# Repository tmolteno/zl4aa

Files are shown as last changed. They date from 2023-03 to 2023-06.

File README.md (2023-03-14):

# ZL4AA Radio Projects

Author: Tim Molteno (ZL4TCM)

Some very basic radios, developed as a way to learn about radio.

## SDR

Very basic radio project. It uses the CH32V305RBT6 RISC-V microprocessor (http://www.wch-ic.com/downloads/CH32V20x_30xDS0_PDF.html). It has the following features
made by Nanjing Qinheng Microelectronics Co. 

* 144 MHz 32-bit RISC-V core (IMAFC instructions)
* Single cycle multiply and hardware division (FPU)
* 64K SRAM
* 4 Op Amps
* 2 x 12-bit DAC !MHz (Dual Channel Mode available for Baseband)
* 2 x 12-bit ADC 1MHz

Reference manual (http://www.wch-ic.com/downloads/CH32FV2x_V3xRM_PDF.html)

### IMAFC

Set of RISC-V instruction extensions.

Integer (M) multiply and divide.
Atomic (A) instructions
Floating Point (F) single-precision
Compressed (C) instructions.

## Architecture

A local oscillator with I/Q outputs.

A switching I/Q mixer to zero IF.

40 dB LNA on Antenna Input for RX.

DAC I,Q -> MIXER -> HPF -> PA

## Gui.

SPI OLED screen, LED, Button1, Button2, Morse Key. Beep through speaker.

## Basic 6m Morse TX

Set LO to 50 MHz. 

Button 1. Increase f
Button 3. Decrease f,
Button 3 ON. Tx on (beep)

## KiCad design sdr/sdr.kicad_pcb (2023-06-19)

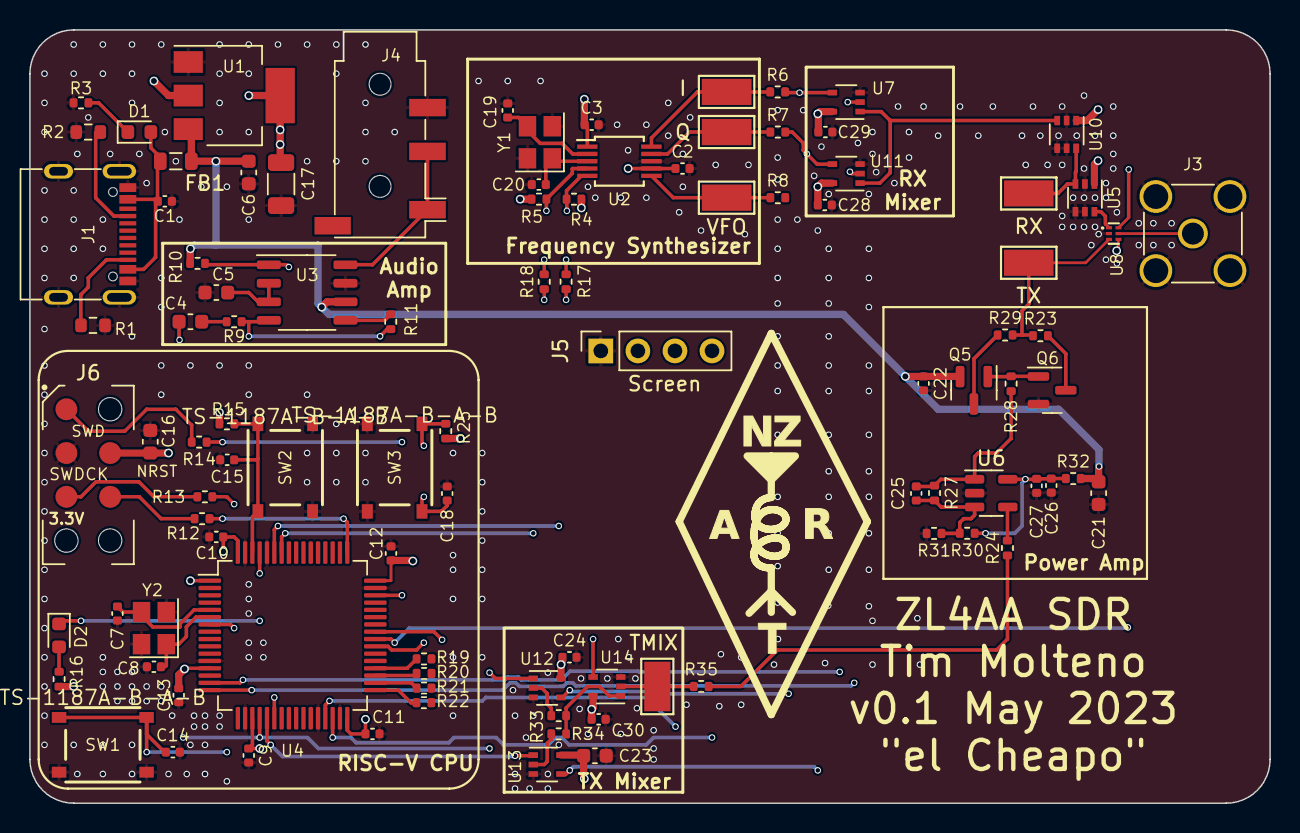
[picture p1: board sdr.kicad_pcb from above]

Board: 4 copper layers, 85.0 x 53.0 mm, 98 parts (0 on the bottom side), 65 nets.

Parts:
C1, C9, C10, C11, C12, C13, C28, C29, C30: 10n; C_0402_1005Metric
C2, C3, C14, C15, C18, C22, C24, C26: 100n; C_0402_1005Metric
C4: 330n; C_0603_1608Metric
C5, C6, C21, C23: 1u; C_0603_1608Metric
C7, C8: 12p; C_0402_1005Metric
C16: 470n; C_0603_1608Metric
C17: 22u; C_1206_3216Metric
C19, C20: 2.2p; C_0402_1005Metric
C25: 0.5pF; C_0402_1005Metric
C27: 1n; C_0402_1005Metric
D1: PWR; D_0603_1608Metric
D2: PB8; D_0603_1608Metric
FB1: GZ2012D101TF; L_0805_2012Metric
J1: USB_C_Receptacle_USB2.0; USB_C_Receptacle_ SHOU_HAN_TYPE-C 16PIN 2MD(073)
J3: Conn_Coaxial; SMA_Amphenol_901-144_Vertical
J4: PJ-320D; Jack_3.5mm_PJ320D_Horizontal
J5: Screen; PinSocket_1x04_P2.54mm_Vertical
J6: swd-connect-5; swd-connect-5-mcu
Q5: AO3400A; SOT-23
Q6: AO3401A; SOT-23
R1, R2: 5.1k; R_0603_1608Metric
R3, R30, R31: 470; R_0402_1005Metric
R4, R5, R10, R15, R25: 10k; R_0402_1005Metric
R6, R7, R8, R35: 0; R_0402_1005Metric
R9, R11: 20k; R_0402_1005Metric
R12, R13, R14, R17, R18, R19, R20, R21, R22, R28: 100; R_0402_1005Metric
R16: 1k; R_0402_1005Metric
R23, R29: 10; R_0402_1005Metric
R24: 120; R_0402_1005Metric
R27: 220; R_0402_1005Metric
R32: 1; R_0402_1005Metric
R33, R34: 47; R_0402_1005Metric
SW1, SW2, SW3: TS-1187A-B-A-B
TP1: VFO; TestPoint_Keystone_5015_Micro-Minature
TP2: Q; TestPoint_Keystone_5015_Micro-Minature
TP3: I; TestPoint_Keystone_5015_Micro-Minature
TP4: RX; TestPoint_Keystone_5015_Micro-Minature
TP5: TX; TestPoint_Keystone_5015_Micro-Minature
TP6: TMIX; TestPoint_Keystone_5015_Micro-Minature
U1: AMS1117-3.3; SOT-223-3_TabPin2
U2: MS5351M; MSOP-10_3x3mm_P0.5mm
U3: LM4871M/TR_C383075; SOP-8_3.9x4.9mm_P1.27mm
U4: CH32V305RBT6; LQFP-64_10x10mm_P0.5mm
U5, U10: BGA2817; SOT-363_SC-70-6
U6: GS8091-TR; SOT-23-5
U7, U11, U12, U13, U14: 74LVC1G66; SOT-353_SC-70-5
U8: FM1630C; DFN-6_L1.1-W0.7-P0.40-BL
Y1, Y2: 25MHz; Crystal_SMD_3225-4Pin_3.2x2.5mm

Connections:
+3.3V: C2.1, C3.1, C9.1, C10.1, C11.1, C12.1, C13.1, C16.1, C17.1, C23.1, C24.1, C28.1, C29.1, C30.1, J5.2, J6.3 (3V3), R4.2, R5.1, R15.1, R16.1, R25.1, U1.2 (VO), U2.1 (VDD), U2.7 (VDDO), U4.1 (VBAT), U4.13 (VDDA), U4.19 (VDD_4), U4.32 (VIO_1), U4.48 (VDD_2), U4.64 (VIO_3), U5.1 (Vcc), U7.5 (VCC), U8.4 (VDD), U10.1 (Vcc), U11.5 (VCC), U12.5 (VCC), U13.5 (VCC), U14.5 (VCC)
+5P: C26.1, C27.1, R30.1, R32.1, U6.5 (V+)
+5V: C6.1, C21.1, C22.1, FB1.2, Q5.2 (S), R10.1, R32.2, U1.3 (VI), U3.6 (VDD)
/Audio Output/AUDIO: C4.2, U4.20 (PA4/ADC4/DAC0), U12.1
/Audio Output/SHUTDOWN: R10.2, U3.1 (Shutdown), U4.22 (PA6/ADC6)
/CPU/ADC_I: U4.15 (PA1/ADC1), U7.2
/CPU/ADC_Q: U4.16 (PA2/ADC2), U11.2
/CPU/DAC_Q: U4.21 (PA5/ADC5/DAC1), U13.1
/CPU/I2C_SCL: R5.2, R18.2, U2.4 (SCL)
/CPU/I2C_SDA: R4.1, R17.2, U2.5 (SDA)
/Freq Synthesizer/LO_I: R6.2, U7.4, U12.4
/Freq Synthesizer/LO_Q: R7.2, U11.4, U13.4
/Mixer I/RF: U7.1, U10.3, U11.1
/TX Amplifier/RF_IN: R24.2, R35.2
/TX Amplifier/RF_OUT: R23.1, R29.2, TP5.1, U8.3 (RF1)
/Tx Mixers/RF_OUT: R35.1, TP6.1, U14.2
GND: C1.2, C2.2, C3.2, C5.2, C6.2, C7.1, C8.1, C9.2, C10.2, C11.2, C12.2, C13.2, C14.2, C15.2, C16.2, C17.2, C18.2, C19.1, C20.2, C21.2, C22.2, C23.2, C24.2, C26.2, C27.2, C28.2, C29.2, C30.2, J1.A1 (GND), J1.A12 (GND), J1.B1 (GND), J1.B12 (GND), J1.S1 (SHIELD), J3.2 (Ext), J4.R2, J5.1, J6.2 (GND), Q6.2 (S), R1.2, R2.2, R3.2, R31.2, SW1.1, SW2.1, SW3.1, U1.1 (GND), U2.8 (GND), U3.7 (GND), U4.12 (VSSA), U4.18 (VSS_4), U4.28 (PB2/BOOT1), U4.31 (VSS_1), U4.47 (VSS_2), U4.60 (BOOT0), U4.63 (VSS_3), U5.2 (G), U5.4 (G), U5.5 (G), U6.2 (V-), U7.3 (GND), U8.2 (GND), U10.2 (G), U10.4 (G), U10.5 (G), U11.3 (GND), U12.3 (GND), U13.3 (GND), U14.3 (GND), Y1.2, Y1.4, Y2.2, Y2.4
KEY: C15.1, R15.2, SW2.2, U4.62 (PB9)
LED: D2.1 (K), U4.61 (PB8)
LEFT: J4.R1, J4.T, U3.8 (VO2)
NRST: C14.1, R13.1, SW1.2, U4.7 (NRST)
unnamed: C4.1, R9.1
unnamed: C25.1, R27.1, R28.1, U6.1
unnamed: C1.1, D1.2 (A), FB1.1, J1.A4 (VBUS), J1.A9 (VBUS), J1.B4 (VBUS), J1.B9 (VBUS)
unnamed: D1.1 (K), R3.1
unnamed: D2.2 (A), R16.2
unnamed: J1.A5 (CC1), R2.1
unnamed: J1.B5 (CC2), R1.1
unnamed: J3.1 (In), U8.5 (ANT)
unnamed: J6.4 (RST), R13.2
unnamed: J6.5 (SWCLK), R12.2
unnamed: J6.1 (SWD), R14.2
unnamed: Q5.3 (D), R29.1
unnamed: Q5.1 (G), Q6.1 (G), R28.2
unnamed: Q6.3 (D), R23.2
unnamed: R33.1, U12.2
unnamed: R33.2, R34.1, U14.1
unnamed: R34.2, U13.2
unnamed: TP4.1, U5.3, U10.6
unnamed: R6.1, TP3.1, U2.10 (CLK0)
unnamed: R7.1, TP2.1, U2.9 (CLK1)
unnamed: R8.1, TP1.1, U2.6 (CLK2)
unnamed: C19.2, U2.2 (XA), Y1.3
unnamed: C20.1, U2.3 (XB), Y1.1
unnamed: C5.1, U3.2 (Bypass), U3.3 (+IN)
unnamed: R9.2, R11.1, U3.4 (-IN)
unnamed: R11.2, U3.5 (VO1)
unnamed: C7.2, U4.5 (OSC_IN/PD0), Y2.3
unnamed: C8.2, U4.6 (OSC_OUT/PD1), Y2.1
unnamed: R18.1, U4.58 (PB6/USB2DM)
unnamed: R17.1, U4.59 (PB7/USB2DP)
unnamed: R22.2, U4.33 (PB12)
unnamed: R21.2, U4.34 (PB13)
unnamed: R20.2, U4.35 (PB14)
unnamed: R19.2, U4.36 (PB15)
unnamed: R24.1, U6.4 (-)
unnamed: U5.6, U8.1 (RF2)
OLED_SCL: J5.3, U4.29 (PB10)
OLED_SDA: J5.4, U4.30 (PB11)
PTT: C18.1, R25.2, SW3.2, U4.39 (PC8)
RX_EN: U4.40 (PC9), U8.6 (VCTL)
SWCLK: R12.1, U4.49 (PA14/SWCLK)
SWDIO: R14.1, U4.46 (PA13/SWDIO)
TXMIX_EN: U4.41 (PA8), U14.4
V_BIAS: C25.2, R27.2, R30.2, R31.1, U6.3 (+)

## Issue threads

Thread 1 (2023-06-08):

Changes for Next Version

tmolteno, 2023-06-08:
- [ ] Reverse Logo on Back
- [ ] Holes for screen to mount firmly. Make a component.
- [ ] Use pogo pins for programming. Make a board that plugs into the Link-E
- [ ]

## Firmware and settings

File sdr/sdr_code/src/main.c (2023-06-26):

#include <ch32v30x.h>
#include <debug.h>
#include "tiny_invaders.h"
#include "hardware.h"
#include "Si5351.h"
#include "oled_min.h"
#include "splash_screen.xbm"
void NMI_Handler(void) __attribute__((interrupt("WCH-Interrupt-fast")));
void HardFault_Handler(void) __attribute__((interrupt("WCH-Interrupt-fast")));
void EXTI9_5_IRQHandler(void)  __attribute__((interrupt(/*"WCH-Interrupt-fast"*/)));

void Delay_Init(void);
void Delay_Ms(uint32_t n);


void KEY_Interrupt_Init(void) {

    GPIO_InitTypeDef GPIO_InitStructure = {0};
    EXTI_InitTypeDef EXTI_InitStructure = {0};
    NVIC_InitTypeDef NVIC_InitStructure = {0};

	/* PB9 'MODE' Key */
    RCC_APB2PeriphClockCmd(RCC_APB2Periph_AFIO | RCC_APB2Periph_GPIOB, ENABLE);
    GPIO_InitStructure.GPIO_Pin = MODE_KEY_PIN;
    GPIO_InitStructure.GPIO_Mode = GPIO_Mode_IPD;
    GPIO_InitStructure.GPIO_Speed = GPIO_Speed_50MHz;
    GPIO_Init(MODE_KEY_PORT, &GPIO_InitStructure);
	
	/* PC8 PTT Key */
	RCC_APB2PeriphClockCmd(RCC_APB2Periph_GPIOC, ENABLE);
    GPIO_InitStructure.GPIO_Pin = PTT_KEY_PIN;
    GPIO_InitStructure.GPIO_Mode = GPIO_Mode_IPU;
    GPIO_InitStructure.GPIO_Speed = GPIO_Speed_50MHz;
    GPIO_Init(PTT_KEY_PORT, &GPIO_InitStructure);

    GPIO_EXTILineConfig(GPIO_PortSourceGPIOB, GPIO_PinSource9);

    EXTI_InitStructure.EXTI_Line = EXTI_Line9;
    EXTI_InitStructure.EXTI_Mode = EXTI_Mode_Interrupt;
    EXTI_InitStructure.EXTI_Trigger = EXTI_Trigger_Falling;
    EXTI_InitStructure.EXTI_LineCmd = ENABLE;
    EXTI_Init(&EXTI_InitStructure);

    NVIC_InitStructure.NVIC_IRQChannel = EXTI9_5_IRQn;
    NVIC_InitStructure.NVIC_IRQChannelPreemptionPriority = 1;
    NVIC_InitStructure.NVIC_IRQChannelSubPriority = 2;
    NVIC_InitStructure.NVIC_IRQChannelCmd = ENABLE;
    NVIC_Init(&NVIC_InitStructure);
}

#include "state.h"
#include <u8g2.h>

extern u8g2_t u8g2;

void u8g2_setup(void);

volatile u8 current_state = STATE_IDLE;
volatile u8 next_state = STATE_IDLE;

/* Global define */
#define N_SAMPLES 64

/* Global Variable */
u16 DAC_Value[N_SAMPLES]={2048,2248,2447,2642,2831,3013,3185,3347,3496,3631,3750,3854,3940,4007,4056,4086,
                         4095,4086,4056,4007,3940,3854,3750,3631,3496,3347,3185,3013,2831,2642,2447,2248,
                         2048,1847,1648,1453,1264,1082,910 ,748 ,599 ,464 ,345 ,241 ,155 ,88  ,39  ,9   ,
                         0   ,9   ,39  ,88  ,155 ,241 ,345 ,464 ,599 ,748 ,910 ,1082,1264,1453,1648,1847};

int main(void)
{
	NVIC_PriorityGroupConfig(NVIC_PriorityGroup_2);
	SystemCoreClockUpdate();
	Delay_Init();

	Delay_Ms(1000);

	GPIO_Pins_Init();
	DAC_Initialize();

	AudioEnable();

	DAC_DMA_Init(&DAC_Value[0], N_SAMPLES);
	DAC_Timer_Init(0x7,24000-1);

    RCC_AHBPeriphClockCmd(RCC_AHBPeriph_RNG, ENABLE);
	RNG_Cmd(ENABLE);

	Synthesizer_Init(100000, 0x77);

    KEY_Interrupt_Init();

	OLED_I2C_init();

	u8g2_setup();

	u8g2_DrawXBM(&u8g2, 0, 0, 128, 64, splash_screen_bits);
 	u8g2_SendBuffer(&u8g2);

	uint8_t ledState = 0;
	while (1)
	{
		if (current_state != next_state) {
			u8g2_ClearBuffer(&u8g2);
			switch (next_state) {
				case STATE_IDLE:
					u8g2_DrawStr(&u8g2,2,30,"IDLE");
					break;
				case STATE_SENDING:
					u8g2_DrawStr(&u8g2,2,30,"TX");
					break;
				case STATE_RECEIVING:
					u8g2_DrawStr(&u8g2,2,30,"RX");
					break;
				case STATE_GAME:
					u8g2_DrawStr(&u8g2,2,30,"GAME");

					tiny_invaders_setup();
					break;
			}
 			u8g2_SendBuffer(&u8g2);
			current_state = next_state;
		}
		switch (current_state) {
			case STATE_IDLE:
				GPIO_WriteBit(BLINKY_GPIO_PORT, BLINKY_GPIO_PIN, ledState);
				ledState ^= 1; // invert for the next run
				Delay_Ms(1000);
				break;
			case STATE_SENDING:
				GPIO_WriteBit(BLINKY_GPIO_PORT, BLINKY_GPIO_PIN, ledState);
				ledState ^= 1; // invert for the next run
				Delay_Ms(100);
				break;
			case STATE_RECEIVING:
				break;
			case STATE_GAME:
				tiny_invaders_loop();
				Delay_Ms(2);
				break;
		}
	}
}

void NMI_Handler(void) {}
void HardFault_Handler(void)
{
	while (1)
	{
	}
}



/*********************************************************************
 * @fn      EXTI9_IRQHandler
 *
 * @brief   This function handles EXTI0 Handler.
 *
 * @return  none
 */
void EXTI9_5_IRQHandler(void)
{
  	if(EXTI_GetITStatus(EXTI_Line9) != RESET)
    {
		switch (current_state) {
			case STATE_IDLE:
				next_state = STATE_SENDING;
				break;
			case STATE_SENDING:
				next_state = STATE_RECEIVING;
				break;
			case STATE_RECEIVING:
				next_state = STATE_GAME;
				break;
			case STATE_GAME:
				next_state = STATE_IDLE;
				break;
		}
        EXTI_ClearITPendingBit(EXTI_Line9); /* Clear Flag */
    }
}

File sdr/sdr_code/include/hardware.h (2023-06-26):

#ifndef __hardware_h__
#define __haredware_h__

#define BLINKY_GPIO_PIN GPIO_Pin_8
#define BLINKY_GPIO_PORT GPIOB


#define I2C_SCL_PIN GPIO_Pin_6
#define I2C_SDA_PIN GPIO_Pin_7

#define DAC_I_PIN GPIO_Pin_4
#define DAC_Q_PIN GPIO_Pin_5
#define AUDIO_SHUTDOWN_PIN GPIO_Pin_6

#define DAC_I_PORT GPIOA
#define DAC_Q_PORT GPIOA
#define AUDIO_SHUTDOWN_PORT GPIOA


#define PTT_KEY_PIN GPIO_Pin_8
#define PTT_KEY_PORT GPIOC

#define MODE_KEY_PIN GPIO_Pin_9
#define MODE_KEY_PORT GPIOB


void GPIO_Pins_Init(void);
void DAC_Initialize(void);
void DAC_Timer_Init(u16 arr,u16 psc);

void DAC_DMA_Init(u16* dacbuff16bit_ptr, u32 buffsize);
void Synthesizer_Init(u32 bound, u16 address);

int PTT_Pressed(void);
int Mode_Pressed(void);

void AudioEnable(void);
void AudioShutdown(void);

#endif // __hardware_h__

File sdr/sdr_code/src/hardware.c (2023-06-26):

#include <ch32v30x.h>
#include "hardware.h"



void GPIO_Pins_Init(void) {
	GPIO_InitTypeDef GPIO_InitStructure = {0};
	RCC_APB2PeriphClockCmd(RCC_APB2Periph_GPIOB, ENABLE);

	GPIO_InitStructure.GPIO_Pin = BLINKY_GPIO_PIN;
	GPIO_InitStructure.GPIO_Mode = GPIO_Mode_Out_PP;
	GPIO_InitStructure.GPIO_Speed = GPIO_Speed_50MHz;
	GPIO_Init(BLINKY_GPIO_PORT, &GPIO_InitStructure);

    RCC_APB2PeriphClockCmd(RCC_APB2Periph_GPIOA, ENABLE);

    /*  Note: In order to avoid parasitic interference and additional power consumption, 
        the corresponding pins of the DAC channel need to be set to analog input (AIN) mode in advance.
    */
    GPIO_InitStructure.GPIO_Pin = DAC_I_PIN;
    GPIO_InitStructure.GPIO_Mode = GPIO_Mode_AIN;
    GPIO_InitStructure.GPIO_Speed = GPIO_Speed_50MHz;
    GPIO_Init(DAC_I_PORT, &GPIO_InitStructure);

    GPIO_InitStructure.GPIO_Pin = DAC_Q_PIN;
    GPIO_InitStructure.GPIO_Mode = GPIO_Mode_AIN;
    GPIO_InitStructure.GPIO_Speed = GPIO_Speed_50MHz;
    GPIO_Init(DAC_Q_PORT, &GPIO_InitStructure);

    GPIO_InitStructure.GPIO_Pin = AUDIO_SHUTDOWN_PIN;
    GPIO_InitStructure.GPIO_Mode = GPIO_Mode_Out_PP;
    GPIO_InitStructure.GPIO_Speed = GPIO_Speed_50MHz;
    GPIO_Init(AUDIO_SHUTDOWN_PORT, &GPIO_InitStructure);

	GPIO_SetBits(DAC_I_PORT, DAC_I_PIN);
    AudioShutdown(); /* For the moment, shut audio down */
}

void AudioEnable(void) {
    GPIO_WriteBit(AUDIO_SHUTDOWN_PORT, AUDIO_SHUTDOWN_PIN, Bit_RESET);
}

void AudioShutdown(void) {
    GPIO_WriteBit(AUDIO_SHUTDOWN_PORT, AUDIO_SHUTDOWN_PIN, Bit_SET);
}

int PTT_Pressed(void) {
    return GPIO_ReadInputDataBit(PTT_KEY_PORT, PTT_KEY_PIN) == Bit_RESET;
}
int Mode_Pressed(void) {
    return GPIO_ReadInputDataBit(MODE_KEY_PORT, MODE_KEY_PIN) == Bit_RESET;
}


/// @brief 
/// @param  
void DAC_Initialize(void) {
    // Now enable the DAC for audio and baseband

    DAC_InitTypeDef  DAC_InitType = {0};

    RCC_APB1PeriphClockCmd(RCC_APB1Periph_DAC, ENABLE);
	DAC_InitType.DAC_Trigger=DAC_Trigger_T8_TRGO;
	DAC_InitType.DAC_WaveGeneration=DAC_WaveGeneration_None;
	DAC_InitType.DAC_OutputBuffer=DAC_OutputBuffer_Disable ;
    DAC_Init(DAC_Channel_1,&DAC_InitType);

	DAC_Cmd(DAC_Channel_1, ENABLE);
	DAC_DMACmd(DAC_Channel_1,ENABLE);
}



/*********************************************************************
 * @fn      TIM8_Init
 *
 * @brief   Initializes TIM8 timer used by the DAC trigger.
 *
 * @param   arr - TIM_Period
 *          psc - TIM_Prescaler
 *
 * @return  none
 */
void DAC_Timer_Init(u16 arr,u16 psc)
{
    TIM_TimeBaseInitTypeDef TIM_TimeBaseInitStructure={0};

    RCC_APB2PeriphClockCmd( RCC_APB2Periph_TIM8, ENABLE );

    TIM_TimeBaseInitStructure.TIM_Period = arr;
    TIM_TimeBaseInitStructure.TIM_Prescaler = psc;
    TIM_TimeBaseInitStructure.TIM_ClockDivision = TIM_CKD_DIV1;
    TIM_TimeBaseInitStructure.TIM_CounterMode = TIM_CounterMode_Down;
    TIM_TimeBaseInitStructure.TIM_RepetitionCounter =  0x00;
    TIM_TimeBaseInit( TIM8, &TIM_TimeBaseInitStructure);

	TIM_SelectOutputTrigger(TIM8, TIM_TRGOSource_Update);
	TIM_Cmd(TIM8, ENABLE);
}




void DAC_DMA_Init(u16* dacbuff16bit_ptr, u32 buffsize) {
    // Now initialize the DMA
    DMA_InitTypeDef DMA_InitStructure={0};
    RCC_AHBPeriphClockCmd(RCC_AHBPeriph_DMA2, ENABLE);

    DMA_StructInit( &DMA_InitStructure);
    /* Note:DAC1--->DMA1.CH3   DAC2--->DMA1.CH4 */
    DMA_InitStructure.DMA_PeripheralBaseAddr = (u32)&(DAC->R12BDHR1);
    DMA_InitStructure.DMA_MemoryBaseAddr = (u32)dacbuff16bit_ptr;
    DMA_InitStructure.DMA_DIR = DMA_DIR_PeripheralDST;
    DMA_InitStructure.DMA_BufferSize = buffsize;
    DMA_InitStructure.DMA_PeripheralInc = DMA_PeripheralInc_Disable;
    DMA_InitStructure.DMA_MemoryInc = DMA_MemoryInc_Enable;
    DMA_InitStructure.DMA_PeripheralDataSize = DMA_PeripheralDataSize_HalfWord;
    DMA_InitStructure.DMA_MemoryDataSize = DMA_MemoryDataSize_HalfWord;
    DMA_InitStructure.DMA_Mode = DMA_Mode_Circular;
    DMA_InitStructure.DMA_Priority = DMA_Priority_VeryHigh;
    DMA_InitStructure.DMA_M2M = DMA_M2M_Disable;

    DMA_Init(DMA2_Channel3, &DMA_InitStructure);
    DMA_Cmd(DMA2_Channel3, ENABLE);
}

void Synthesizer_Init(u32 bound, u16 address)
{
    GPIO_InitTypeDef GPIO_InitStructure = {0};
    I2C_InitTypeDef  I2C_InitStructure = {0};

    RCC_APB2PeriphClockCmd(RCC_APB2Periph_GPIOB, ENABLE);
    RCC_APB1PeriphClockCmd(RCC_APB1Periph_I2C1, ENABLE);

	/* I2S interface pins */
    GPIO_InitStructure.GPIO_Pin = I2C_SCL_PIN;
    GPIO_InitStructure.GPIO_Mode = GPIO_Mode_AF_OD;
    GPIO_InitStructure.GPIO_Speed = GPIO_Speed_50MHz;
    GPIO_Init(GPIOB, &GPIO_InitStructure);

    GPIO_InitStructure.GPIO_Pin = I2C_SDA_PIN;
    GPIO_InitStructure.GPIO_Mode = GPIO_Mode_AF_OD;
    GPIO_InitStructure.GPIO_Speed = GPIO_Speed_50MHz;
    GPIO_Init(GPIOB, &GPIO_InitStructure);

    I2C_InitStructure.I2C_ClockSpeed = bound;
    I2C_InitStructure.I2C_Mode = I2C_Mode_I2C;
    I2C_InitStructure.I2C_DutyCycle = I2C_DutyCycle_2;
    I2C_InitStructure.I2C_OwnAddress1 = 0x77; // Unimportant Init
    I2C_InitStructure.I2C_Ack = I2C_Ack_Enable;
    I2C_InitStructure.I2C_AcknowledgedAddress = I2C_AcknowledgedAddress_7bit;
    I2C_Init(I2C1, &I2C_InitStructure);

    I2C_Cmd(I2C1, ENABLE);
    I2C_AcknowledgeConfig(I2C1, ENABLE);

    while( I2C_GetFlagStatus( I2C1, I2C_FLAG_BUSY ) != RESET );
}

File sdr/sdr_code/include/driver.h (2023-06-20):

// ===================================================================================
// Tiny Joypad Drivers for CH32V305                                          * v1.0 *
// ===================================================================================
//
// MCU abstraction layer.
// 2023 by Stefan Wagner:   https://github.com/wagiminator

#pragma once

#ifdef __cplusplus
extern "C" {
#endif

#include <stdbool.h>
#include <debug.h>
#include "oled_min.h"

// Pin assignments
#define PIN_ACT     GPIO_Pin_8   // pin conected to direction buttons: PTT Button PC8
#define GPIO_ACT    GPIOC

// Joypad calibration values
#define JOY_N       197   // joypad UP
#define JOY_NE      259   // joypad UP + RIGHT
#define JOY_E       90    // joypad RIGHT
#define JOY_SE      388   // joypad DOWN + RIGHT
#define JOY_S       346   // joypad DOWN
#define JOY_SW      616   // joypad DOWN + LEFT
#define JOY_W       511   // joypad LEFT
#define JOY_NW      567   // JOYPAD UP + LEFT
#define JOY_DEV     20    // deviation

// Sound enable
#define JOY_SOUND   1     // 0: no sound, 1: with sound

// Game slow-down delay
#define JOY_SLOWDOWN()    Delay_Ms(10)

// Init driver
//tatic void JOY_init(void) {
 // PIN_input_AN(PIN_PAD);
 // PIN_input_PU(PIN_ACT);
 // PIN_output(PIN_BEEP);
 // PIN_high(PIN_BEEP);
 // OLED_init();
 // ADC_init();
 // ADC_input(PIN_PAD);
//}

// OLED commands
#define JOY_OLED_end              OLED_I2C_stop
#define JOY_OLED_send(b)          OLED_I2C_write(b)
#define JOY_OLED_send_command(c)  OLED_send_command(c)
#define JOY_OLED_data_start(y)    {OLED_setpos(0,y);OLED_data_start();}

// Buttons
bool JOY_act_pressed(void) {
  return(!GPIO_ReadInputDataBit(GPIO_ACT, PIN_ACT));
}

bool JOY_act_released(void) {
  return(!JOY_act_pressed());
}

inline bool JOY_pad_pressed(void) {
  return 0; // (ADC_read() > 10);
}

inline bool JOY_pad_released(void) {
  return !JOY_pad_pressed();
}

inline bool JOY_all_released(void) {
  return(JOY_act_released() && JOY_pad_released());
}


#if 0
static inline uint8_t JOY_up_pressed(void) {
 uint16_t val = ADC_read();
 return(   ((val > JOY_N  - JOY_DEV) && (val < JOY_N  + JOY_DEV))
         | ((val > JOY_NE - JOY_DEV) && (val < JOY_NE + JOY_DEV))
         | ((val > JOY_NW - JOY_DEV) && (val < JOY_NW + JOY_DEV)) );
}

static inline uint8_t JOY_down_pressed(void) {
 uint16_t val = ADC_read();
 return(   ((val > JOY_S  - JOY_DEV) && (val < JOY_S  + JOY_DEV))
         | ((val > JOY_SE - JOY_DEV) && (val < JOY_SE + JOY_DEV))
         | ((val > JOY_SW - JOY_DEV) && (val < JOY_SW + JOY_DEV)) );
}
#endif

static inline uint8_t JOY_left_pressed(void) {
#if 0
 uint16_t val = ADC_read();
 return(   ((val > JOY_W  - JOY_DEV) && (val < JOY_W  + JOY_DEV))
         | ((val > JOY_NW - JOY_DEV) && (val < JOY_NW + JOY_DEV))
         | ((val > JOY_SW - JOY_DEV) && (val < JOY_SW + JOY_DEV)) );
#else 
  return 0;
#endif
}

static inline uint8_t JOY_right_pressed(void) {
#if 0
 uint16_t val = ADC_read();
 return(   ((val > JOY_E  - JOY_DEV) && (val < JOY_E  + JOY_DEV))
         | ((val > JOY_NE - JOY_DEV) && (val < JOY_NE + JOY_DEV))
         | ((val > JOY_SE - JOY_DEV) && (val < JOY_SE + JOY_DEV)) );
#else
  return 0;
#endif
}

// Buzzer
void JOY_sound(uint8_t freq, uint8_t dur) {
  #if 0
  while(dur--) {
    #if JOY_SOUND == 1
    if(freq) PIN_low(PIN_BEEP);
    #endif
    DLY_us(255 - freq);
    PIN_high(PIN_BEEP);
    DLY_us(255 - freq);
  }
  #endif /* 0*/
}

// Pseudo random number generator
uint16_t rnval = 0xACE1;
uint16_t JOY_random(void) {
  rnval = (rnval >> 0x01) ^ (-(rnval & 0x01) & 0xB400);
  return rnval;
}

// Delays
#define JOY_DLY_ms    Delay_Ms
#define JOY_DLY_us    Delay_Us

// Additional Defines
#define abs(n) ((n>=0)?(n):(-(n)))

long map(long x, long in_min, long in_max, long out_min, long out_max) {
  return (x - in_min) * (out_max - out_min) / (in_max - in_min) + out_min;
}

#ifdef __cplusplus
};
#endif

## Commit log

2023-03-14 Added microprocessor
    [audio_out.kicad_sch, freq_synth.kicad_sch, sdr.kicad_sch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]
2023-03-17 Added 3.3V LDO and CPU sheet
    [cpu.kicad_sch, sdr.kicad_sch, usb_power.kicad_sch]
2023-03-20 Update lots of things. Now have basic CPU as well as some crude mixers
    [audio_out.kicad_sch, cpu.kicad_sch, freq_synth.kicad_sch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]
2023-03-24 Added ST-link 6-pin 0.1 programming header
    [audio_out.kicad_sch, cpu.kicad_sch, freq_synth.kicad_sch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]
2023-03-25 Tighten up design layout.
    [audio_out.kicad_sch, cpu.kicad_sch, freq_synth.kicad_sch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]
2023-03-25 Added tx amp and mixer
    [tx_amp.kicad_sch, tx_mix.kicad_sch]
2023-03-30 Updated the mixer to include some dedicated switches (Gainsail goes to 300 MHz)
    [mixer_i.kicad_sch, sdr.kicad_sch]
2023-04-05 Many fixes. Updated mixers to use the analog switches rather than discretes.
    [audio_out.kicad_sch, cpu.kicad_sch, mixer_i.kicad_sch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]
2023-05-08 Update schematic to kicad 7. Add IQ correction to models
    [audio_out.kicad_sch, cpu.kicad_sch, freq_synth.kicad_sch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]
2023-05-10 Update to KiCAD 7
    [sdr.kicad_pcb]
2023-05-19 Complete layout
    [cpu.kicad_sch, freq_synth.kicad_sch, mixer_i.kicad_sch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]
2023-05-19 First version 0.1 completed
    [audio_out.kicad_sch, cpu.kicad_sch, freq_synth.kicad_sch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]
2023-05-19 Update the via size. Reduce footprints outside board.
    [audio_out.kicad_sch, cpu.kicad_sch, freq_synth.kicad_sch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]
2023-05-20 Convert to a 4-layer board.
    [audio_out.kicad_sch, mixer_i.kicad_sch, sdr.kicad_pcb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]
2023-05-20 Update logo to work with silkscreen layers
2023-06-08 Added code first draft
    [cpu.kicad_sch]
2023-06-11 Modify the I2C address to shift it left by one bit??!. I2C now works
2023-06-14 Add corrected quadrature synthesis code with band plans
    [main.c]
2023-06-15 Add symbols and footprints for SWD-Connect
2023-06-19 Update footprints, and add an swd-connect-5
    [audio_out.kicad_sch, cpu.kicad_sch, sdr.kicad_pcb]
2023-06-19 I have interrupts going
2023-06-20 Added extra pullup resistors on the OLED i2C. Changed the Synthesizer pullups to 2.2k from 10k
    [cpu.kicad_sch, freq_synth.kicad_sch]
